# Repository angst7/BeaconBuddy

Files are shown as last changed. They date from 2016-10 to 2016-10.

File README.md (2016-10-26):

#BeaconBuddy#

nRF52832 based beacon design

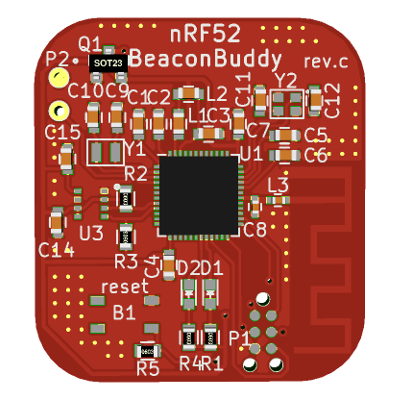
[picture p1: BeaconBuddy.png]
BeaconBuddy rev.c

Simple reference design in a 1"x1.2" form factor with CR2032 battery holder.  Rev. A Tested to work with examples from the nRF52 SDK v11.0.0, but no
guarantees as to the effectiveness of the antenna.  

This design is related to the [nRF52Beacon] (https://github.com/angst7/nRF52beacon) project with the addition of A BME280 Sensor for pressure, temperature, 
and humidity readings.  It also breaks out GPIO/AIn pin P0.02.

** Revision History ** 
- Rev. A is tested and working, please clone the rev_a branch for that version.
- 10/22/2016: Rev. B removed ST humidity sensor, replaced BMP280 with BME280, and replaced diode battery polarity protection with a FET.
- 10/23/2016: Rev. C adds a reset button, and second LED
- This is the Rev. C version.  It is not yet tested with real hardware, but should be fine.

##License##

This work is licensed under [CC Attribution 3.0 United States](https://creativecommons.org/licenses/by/3.0/us/).

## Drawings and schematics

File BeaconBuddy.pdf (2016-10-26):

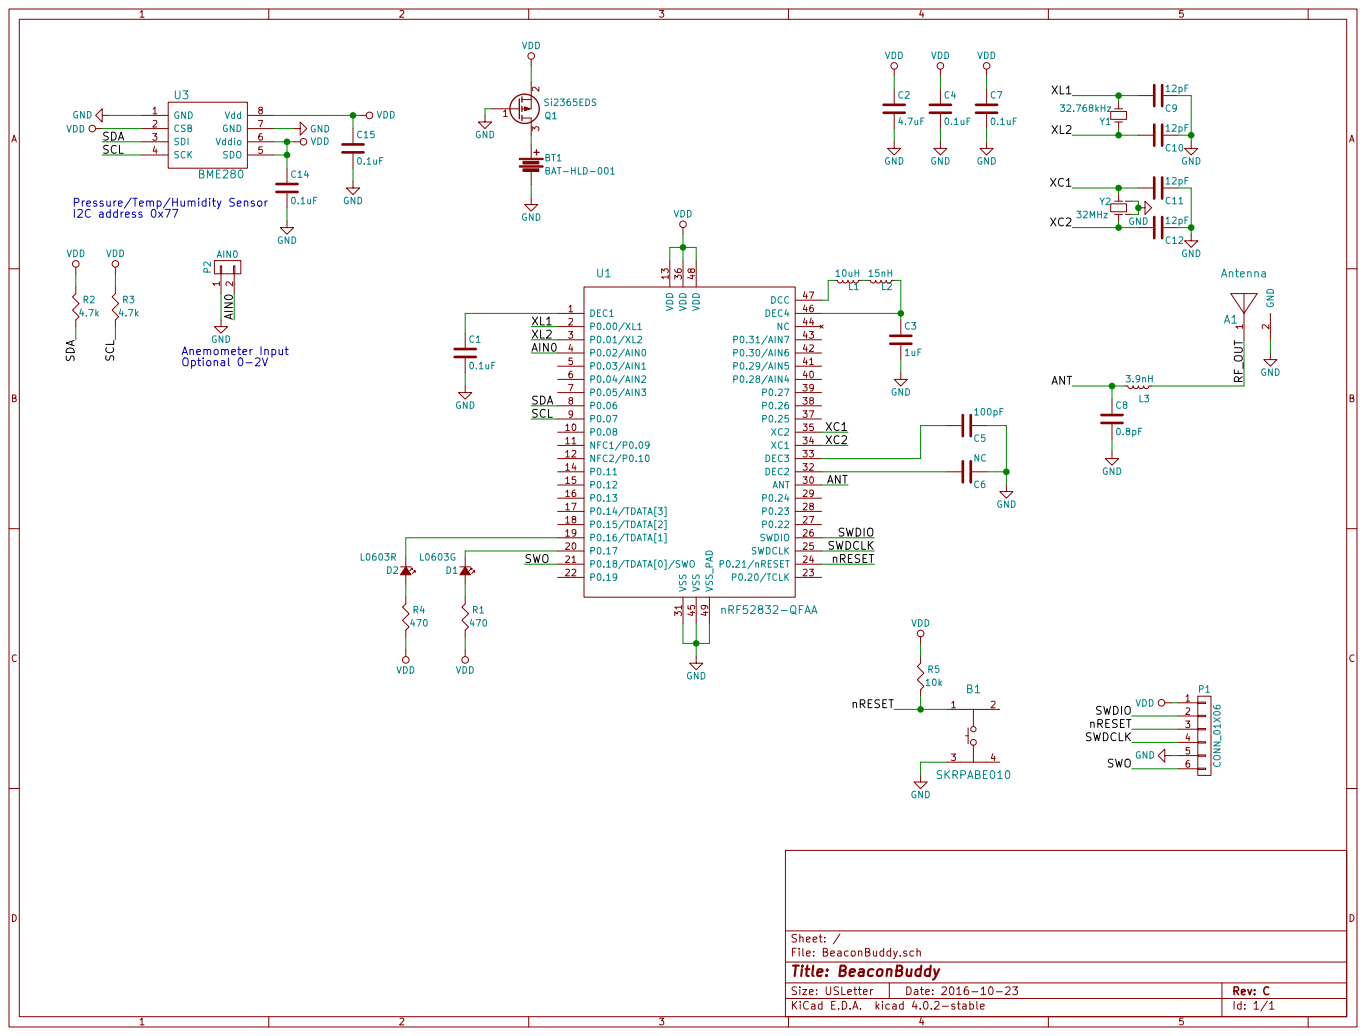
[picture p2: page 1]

File: BeaconBuddy.sch Sheet: /
Id: 1/1 Title: BeaconBuddy

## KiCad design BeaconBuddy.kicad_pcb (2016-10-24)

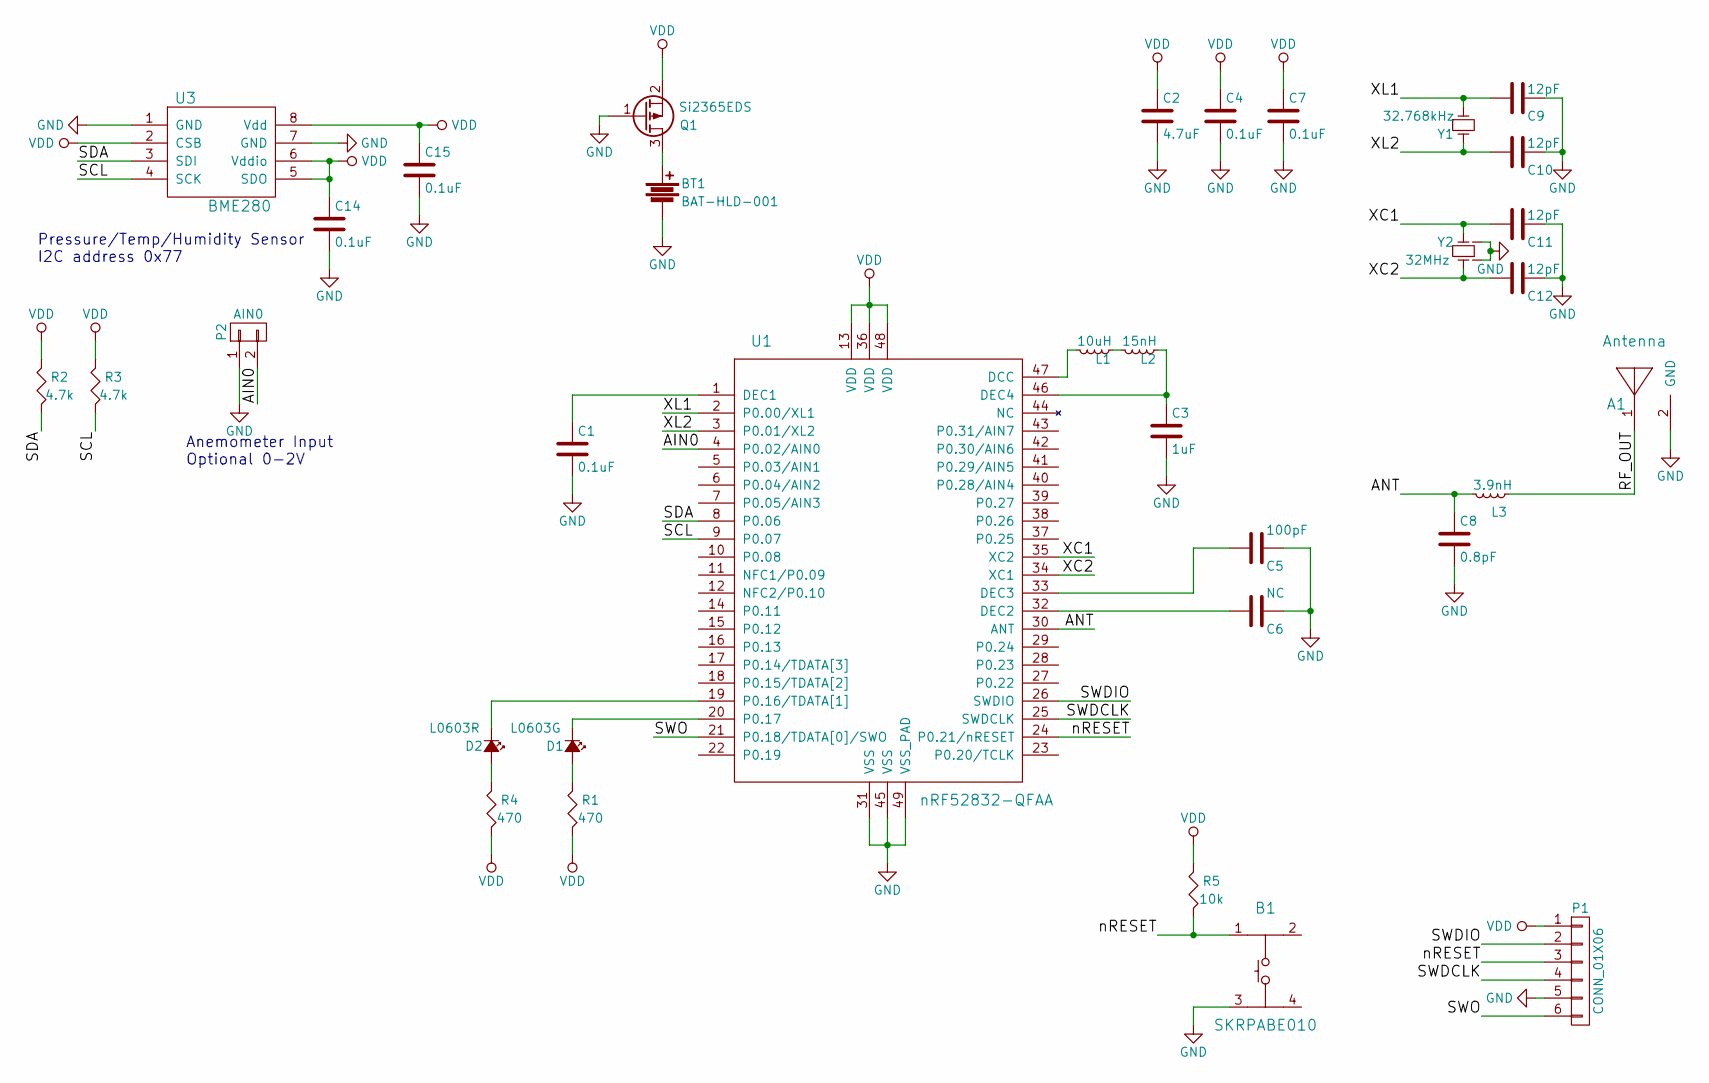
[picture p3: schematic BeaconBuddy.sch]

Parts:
A1: Antenna; Antenna-2.45GHZ
B1: SKRPABE010
BT1: BAT-HLD-001; BATT-HLD-001
C1, C4, C7, C14, C15: 0.1uF; C_0603
C2: 4.7uF; C_0603
C3: 1uF; C_0603
C5: 100pF; C_0603
C6: NC; C_0603
C8: 0.8pF; C_0402
C9, C10, C11, C12: 12pF; C_0603
D1: L0603G; LED_0603
D2: L0603R; LED_0603
L1: 10uH; C_0603
L2: 15nH; C_0603
L3: 3.9nH; C_0402
P1: CONN_01X06; TC2030-MCP-NL
P2: AIN0; CONN_100mil_1x2
Q1: Si2365EDS; SOT-23
R1, R4: 470; R_0603
R2, R3: 4.7k; R_0603
R5: 10k; R_0603
U1: nRF52832-QFAA; UQFN-48-1EP_6x6mm_Pitch0.4mm
U3: BME280; Bosch_LGA8_2.5x2.5
Y1: 32.768kHz; Crystal_ABS06
Y2: 32MHz; Crystal_ABM11

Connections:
/AIN0: P2.2, U1.4 (P0.02/AIN0)
/ANT: C8.1, L3.2, U1.30 (ANT)
/RF_OUT: A1.1, L3.1
/SCL: R3.2, U1.9 (P0.07), U3.4 (SCK)
/SDA: R2.2, U1.8 (P0.06), U3.3 (SDI)
/SWDCLK: P1.4, U1.25 (SWDCLK)
/SWDIO: P1.2, U1.26 (SWDIO)
/SWO: P1.6, U1.21 (P0.18/TDATA[0]/SWO)
/XC1: C11.2, U1.35 (XC2), Y2.3
/XC2: C12.2, U1.34 (XC1), Y2.1
/XL1: C9.2, U1.2 (P0.00/XL1), Y1.1
/XL2: C10.2, U1.3 (P0.01/XL2), Y1.2
/nRESET: B1.1, P1.3, R5.2, U1.24 (P0.21/nRESET)
GND: A1.2 (GND), B1.3, BT1.2, C1.2, C2.2, C3.2, C4.2, C5.1, C6.1, C7.2, C8.2, C9.1, C10.1, C11.1, C12.1, C14.2, C15.2, P1.5, P2.1, Q1.1 (G), U1.31 (VSS), U1.45 (VSS), U1.49 (VSS_PAD), U3.1 (GND), U3.7 (GND), Y2.2, Y2.4
unnamed: BT1.1, Q1.3 (D)
unnamed: C1.1, U1.1 (DEC1)
unnamed: C3.1, L2.1, U1.46 (DEC4)
unnamed: C5.2, U1.33 (DEC3)
unnamed: C6.2, U1.32 (DEC2)
unnamed: D1.1 (K), U1.20 (P0.17)
unnamed: D1.2 (A), R1.1
unnamed: D2.1 (K), U1.19 (P0.16/TDATA[1])
unnamed: D2.2 (A), R4.1
unnamed: L1.1, L2.2
unnamed: L1.2, U1.47 (DCC)
VDD: C2.1, C4.1, C7.1, C14.1, C15.1, P1.1, Q1.2 (S), R1.2, R2.1, R3.1, R4.2, R5.1, U1.13 (VDD), U1.36 (VDD), U1.48 (VDD), U3.2 (CSB), U3.5 (SDO), U3.6 (Vddio), U3.8 (Vdd)

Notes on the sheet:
Pressure/Temp/Humidity Sensor I2C address 0x77
Anemometer Input Optional 0-2V

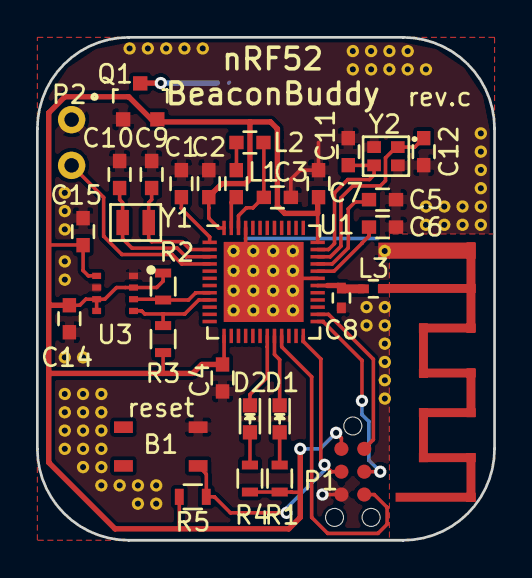
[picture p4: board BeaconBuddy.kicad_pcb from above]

Board: 2 copper layers, 25.4 x 27.9 mm, 34 parts (1 on the bottom side), 26 nets.

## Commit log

2016-07-16 Inital commit
    [BeaconBuddyH.kicad_pcb, BeaconBuddyH.sch]
2016-07-16 Added Temp/Humidity sensor
    [BeaconBuddyH.kicad_pcb, BeaconBuddyH.sch]
2016-07-16 Added Pressure Sensor
    [BeaconBuddyH.kicad_pcb, BeaconBuddyH.sch]
2016-07-16 Added optional Anemometer/Analog Input
    [BeaconBuddyH.kicad_pcb, BeaconBuddyH.sch]
2016-07-17 Fixed ground pin issue:
    [BeaconBuddyH.kicad_pcb]
2016-08-20 Fixed Names
    [BeaconBuddy.kicad_pcb, BeaconBuddy.sch]
2016-08-20 Updated Silk
    [BeaconBuddy.kicad_pcb]
2016-10-23 Switch to PMOS battery protection
    [BeaconBuddy.sch]
2016-10-23 Switch to BME280, update PCB
    [BeaconBuddy.kicad_pcb, BeaconBuddy.sch]
2016-10-23 Update schematic date and revision to Rev.B
    [BeaconBuddy.sch]
2016-10-23 Add reset switch, second LED
    [BeaconBuddy.sch]
2016-10-23 Update PCB for rev.C
    [BeaconBuddy.kicad_pcb, BeaconBuddy.sch]
2016-10-24 Update Readme for rev. C
    [BeaconBuddy.kicad_pcb]
2016-10-26 Add schematic, image for rev.c
    [BeaconBuddy.sch]
